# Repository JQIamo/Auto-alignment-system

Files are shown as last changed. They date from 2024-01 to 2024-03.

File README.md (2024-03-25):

# Source Code for Autoalignment System

This git repository contains the entire source code for the autoalignment
system described in {link to the paper}. It includes:

- `src/`: The firmware for the microcontroller (Teensy 4.1).
- `scripts/`: The python scripts, run on a host PC, to communicate with the microcontroller
  for manual control and diagnostic purposes.
- `calibration/`: A Jupyter notebook that calculate the $A$ matrix from calibration data.
-  `eagle/`: Eagle schematic and board files for fabricating the main control board and the detector boards.

Instructions for how to compile and use the source code are documented in each
individual folder.

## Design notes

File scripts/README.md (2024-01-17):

## Utility Scripts For Communication And Beam Visualization

The communication between the host PC and the microcontroller is achieved
through the serial connection to the microcontroller.

In order to have multiple scripts communicating with the microcontroller at the
same time, all communication are relayed through the script `comm.py`, which
talks to other scripts through ZMQ sockets.

- `comm.py`: Communication host. Dispatch the requests from other scripts to
  the microcontroller.
- `beam_visualize.py`: A GUI program, displays current beam position and
  the beam trajectory history.
- `disp_intensity.py`: A GUI program, displays the beam intensity history. This
  is for troubleshooting laser power fluctuations.
- `interactive_prompt.py`: Provide an interactive prompt, where the user can
  type in commands and those commands are relayed to the microcontroller. This
  is the primary way of manually controlling the microcontroller.
- `move_motor.py`: Move the motor back and forth and collecting the PSD
  readings at the same time. This is for acquiring the calibration data.
- `utils.py`: Utilities functions.

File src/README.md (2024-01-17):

## Firmware for Teensy 4.1 Microcontroller

The firmware presented here is a self-contained Arduino project. It performs
the autoalignment task by itself at the request of a host PC.

### To Compile

The most straight-forward way of setting up the development environment is to
install the [Arduino IDE with teensy packages](https://www.pjrc.com/teensy/td_download.html).
Another way is to install the [`arduino-cli`](https://arduino.github.io/arduino-cli/0.35/)
and manually add the support of Teensy to it (see [the tutorial here](
https://arduino.github.io/arduino-cli/0.35/getting-started/#adding-3rd-party-cores) ).

The code makes use of FreeRTOS for task management, as described in the
manuscript. To compile, it is necessary to install the Arduino package
[`tsandmann/freertos-teensy`](https://github.com/tsandmann/freertos-teensy)
first.

Assuming `arduino-cli` is installed, this can be done by running
```
arduino-cli lib install --git-url https://github.com/tsandmann/freertos-teensy
```
To compile, go the `src/` folder and run
```
arduino-cli compile --build-path build --fqbn teensy:avr:teensy41 main
```

The compiled hex file will be outputted into `build/` folder.

Note that the upload functionality provided in Arduino is not very mature. A
more reliable way is to download
[`teensy_loader_cli`](https://www.pjrc.com/teensy/loader_cli.html) to upload
the hex file to the Teensy:
```
./teensy_loader_cli --mcu=TEENSY41 -s -v build/main.ino.hex
```

### Descriptions For Each File

- `BoardConnection.h`: Describing the pin connections and other hardware
  setups, including the PSD calibration information.
- `PositionMotionMatrices.h`: Storing the A-matrix calibration.
- `main.ino`: Initializing all tasks, interfacing the serial interface and
  dispatching control calls.
- `BeamDetection.cpp`: Reading PSD data, converting to position information.
-  `BeamPositionControl.cpp`: Calculating the motor movement needed to move
   from the current beam position to the desired beam position.
- `MotorControl.cpp`: Controlling the motors.
- `PeakDetection.cpp`: Algorithms to detect the peaks from the scanned cavity
  signals. This is part optional and can be disabled in `main.ino`.

### Before Use

Calibrations for the PSDs and the A-matrix are required for successful
operation. Those calibrations should be performed as instructed in
`calibration/` and the results should be stored in `BoardConnection.h`
and `PositionMotionMatrices.h`.

### Control Interface

When the microcontroller is running, it listens to the serial port for incoming
instructions:
- `pp`: Print beam position, in PSD units.
- `m {n} {step}`: Move the `n`-th motor with number of steps specified by
  `{step}`.
- `mp {x1} {x2} {y1} {y2}`: Move the beam to position specified by (`x1`, `y1`,
  `x2`, `y2`). This is the very command to achieve "autoalignment".
- `unmute`: Start PSD position logging. Useful when running calibrations.
- `mute`: Stop PSD position logging.

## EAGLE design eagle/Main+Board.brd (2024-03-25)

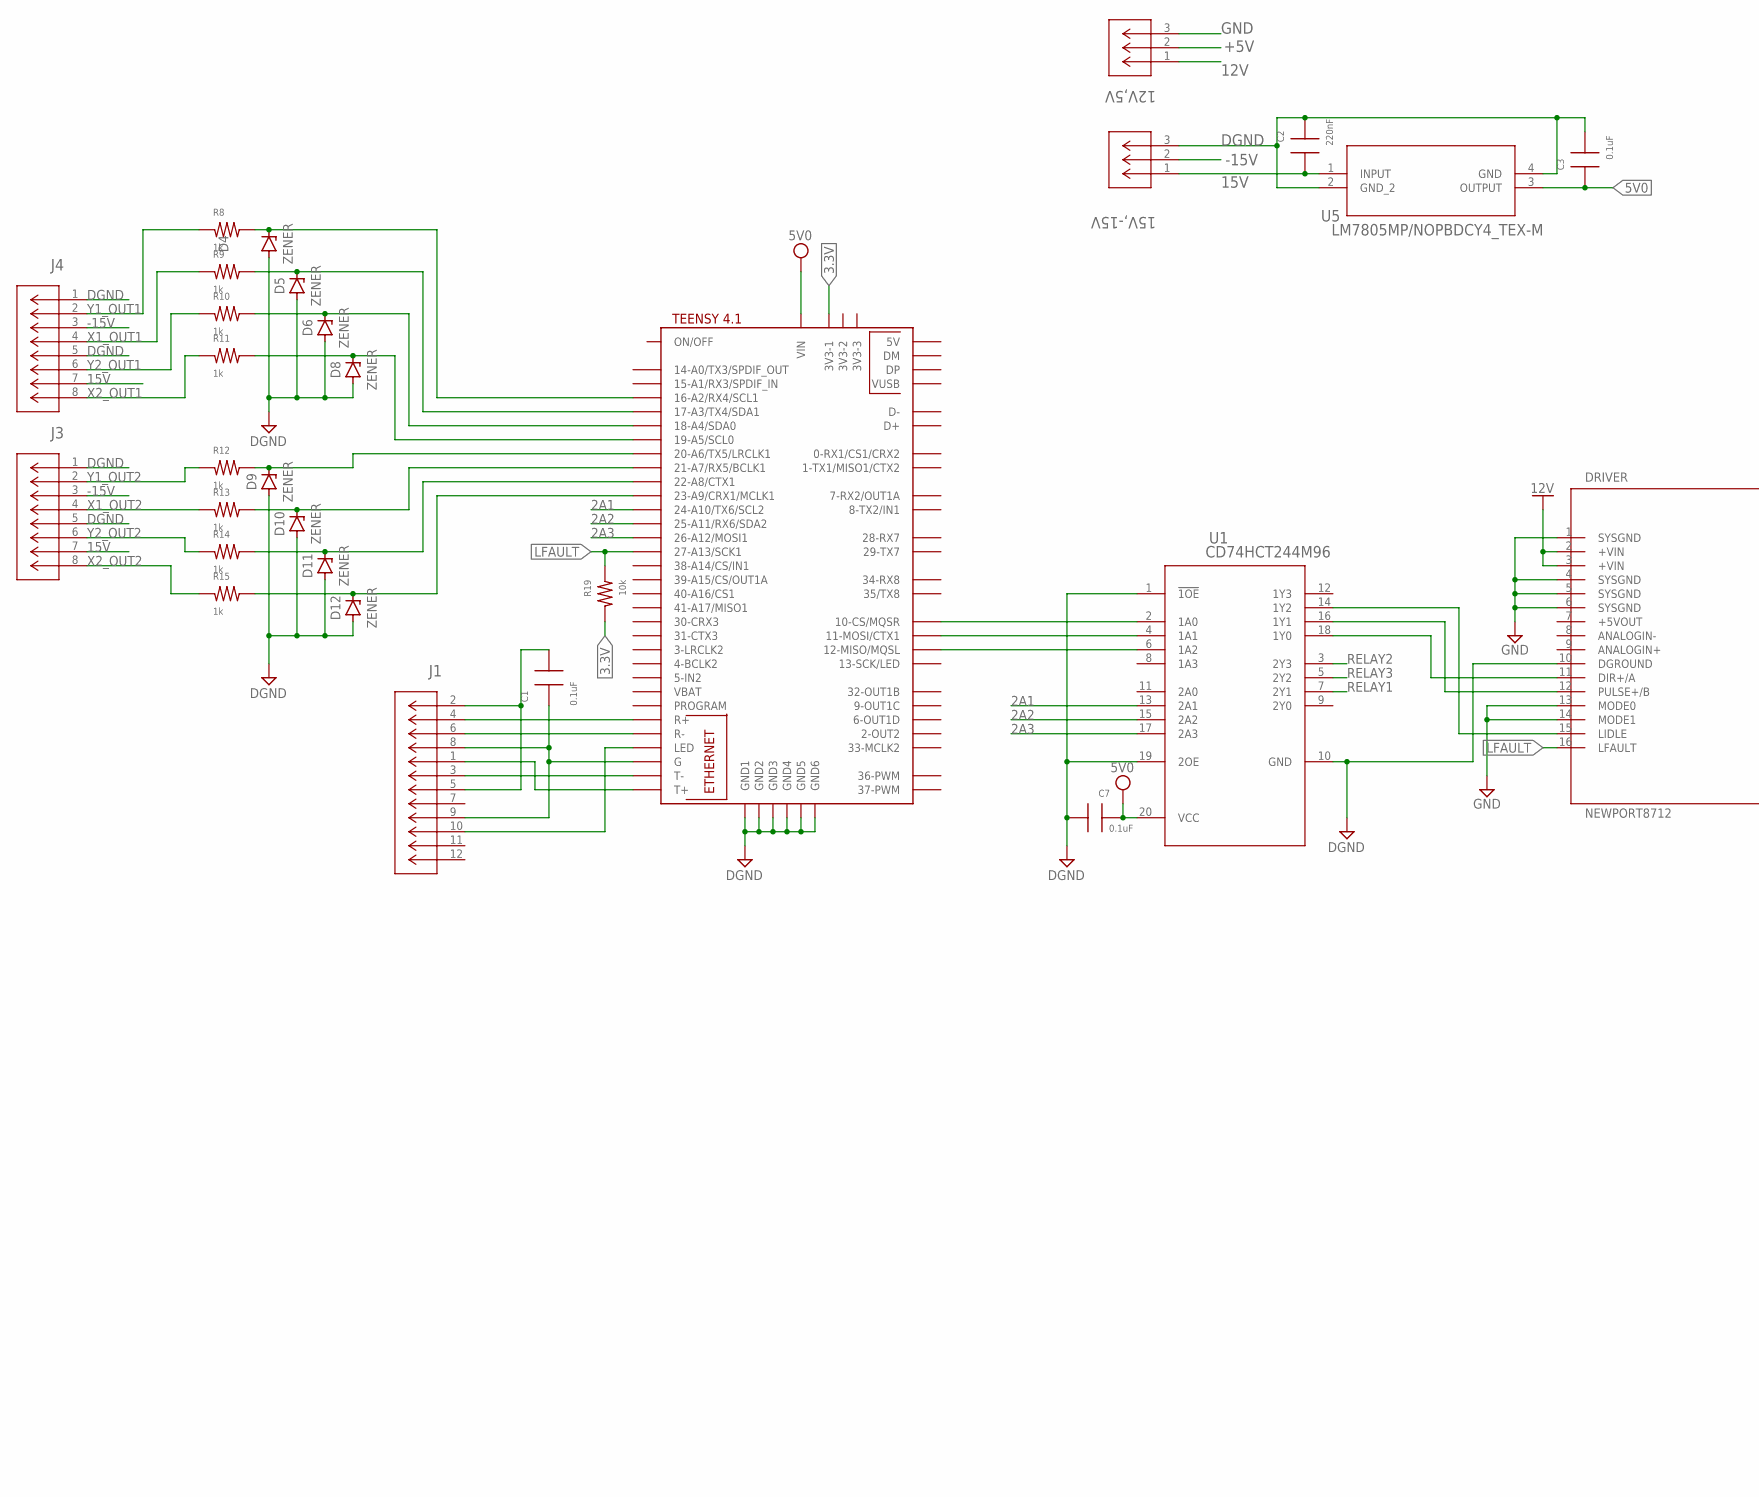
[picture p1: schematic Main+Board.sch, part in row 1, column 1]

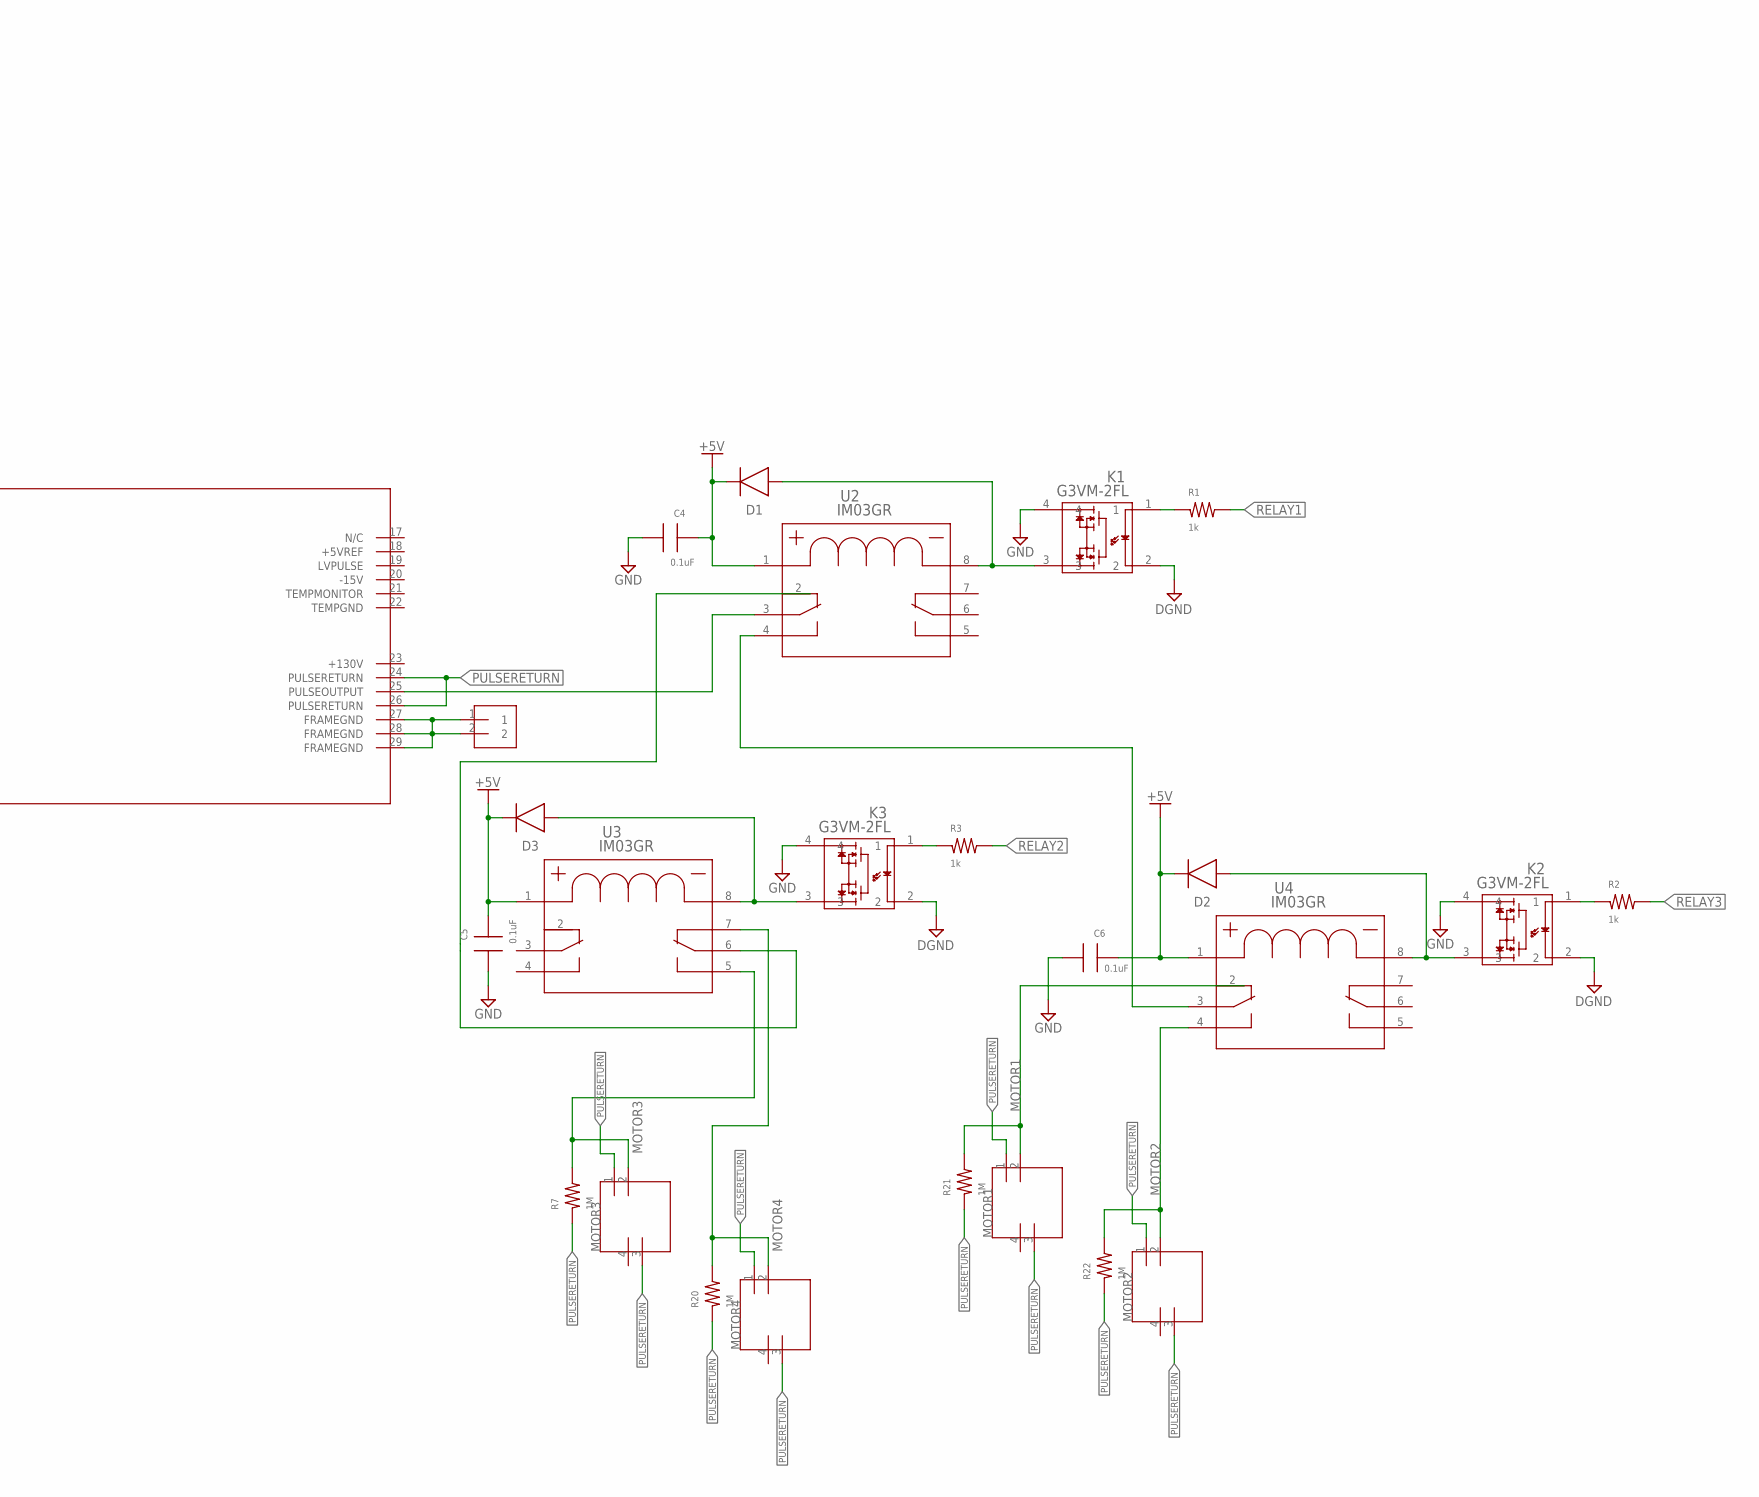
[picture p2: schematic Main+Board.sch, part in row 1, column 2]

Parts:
12V,5V, 15V,-15V: 1729021; CONN_1729021_PXC; DIGIKEY 277-1237-ND
C1, C3, C4, C5, C6, C7: 0.1uF; 0603; DIGIKEY 478-7018-1-ND
C2: 220nF; 0603; DIGIKEY 732-7991-1-ND
D1, D2, D3: 1N4448W; SOD3715X135; DIGIKEY 2721-1N4148WTR-ND
D4, D5, D6, D8, D9, D10, D11, D12: ZENER; SODFL3718X115; DIGIKEY 846-KDZVTR3.3BCT-ND
DRIVER: NEWPORT8712
J1: J1B1211CCD; CONN12_J1B1211CCD_WIZ; DIGIKEY 1278-1052-ND
J3, J4: 75869-332LF; CONN_332LF_AMP; DIGIKEY 609-5123-ND
K1, K2, K3: G3VM-2FL; A-DIP4_THD_OMR; DIGIKEY Z2711-ND
MOTOR1, MOTOR2, MOTOR3, MOTOR4: TM5RJ3-44; DIGIKEY H11287-ND
R1, R2, R3, R8, R9, R10, R11, R12, R13, R14, R15: 1k; 0603; DIGIKEY P123733CT-ND
R7, R20, R21, R22: 1M; 1210; DIGIKEY 13-RC1210FR-071MLCT-ND
R19: 10k; 0603; DIGIKEY YAG1236CT-ND
U1: CD74HCT244M96; DW20; DIGIKEY 296-14552-1-ND
U2, U3, U4: IM03GR; RELAY8-239X396_230; DIGIKEY PB1061CT-ND
U5: LM7805MP/NOPBDCY4_TEX-M; DCY4_TEX-M; DIGIKEY 296-44517-1-ND
U$1: TEENSY41; DIGIKEY 1568-DEV-16771-ND
U$2: 360272; DIGIKEY 1849-1246-ND

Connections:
2A1: U1.13 (2A1), U$1.24-A10/TX6/SCL2
2A2: U1.15 (2A2), U$1.25-A11/RX6/SDA2
2A3: U1.17 (2A3), U$1.26-A12/MOSI1
3.3V: R19.2, U$1.3V3-1
5V0: C3.1, C7.2, U1.20 (VCC), U5.3 (OUTPUT), U$1.VIN
12V: 12V,5V.1, DRIVER.2 (+VIN), DRIVER.3 (+VIN)
15V: 15V,-15V.1, C2.1, J3.7, J4.7, U5.1 (INPUT)
+5V: 12V,5V.2, C4.2, C5.2, C6.2, D1.1 (C), D2.1 (C), D3.1 (C), U2.1, U3.1, U4.1
-15V: 15V,-15V.2, J3.3, J4.3
DGND: 15V,-15V.3, C2.2, C3.2, C7.1, D4.2 (A), D5.2 (A), D6.2 (A), D8.2 (A), D9.2 (A), D10.2 (A), D11.2 (A), D12.2 (A), DRIVER.10 (DGROUND), J3.1, J3.5, J4.1, J4.5, K1.2, K2.2, K3.2, U1.1 (!1OE), U1.10 (GND), U1.19 (2OE), U5.2 (GND_2), U5.4 (GND), U$1.GND1, U$1.GND2, U$1.GND3, U$1.GND4, U$1.GND5, U$1.GND6
FRAMEGND: DRIVER.27 (FRAMEGND), DRIVER.28 (FRAMEGND), DRIVER.29 (FRAMEGND), U$2.1, U$2.2
GND: 12V,5V.3, C4.1, C5.1, C6.1, DRIVER.1 (SYSGND), DRIVER.4 (SYSGND), DRIVER.5 (SYSGND), DRIVER.6 (SYSGND), DRIVER.13 (MODE0), DRIVER.14 (MODE1), K1.4, K2.4, K3.4
LFAULT: DRIVER.16 (LFAULT), R19.1, U$1.27-A13/SCK1
MOTOR1: MOTOR1.2, R21.2, U4.2
MOTOR2: MOTOR2.2, R22.2, U4.4
MOTOR3: MOTOR3.2, R7.2, U3.5
MOTOR4: MOTOR4.2, R20.2, U3.7
unnamed: D10.1 (C), R13.2, U$1.21-A7/RX5/BCLK1
unnamed: K1.1, R1.1
unnamed: D4.1 (C), R8.2, U$1.16-A2/RX4/SCL1
unnamed: D5.1 (C), R9.2, U$1.17-A3/TX4/SDA1
unnamed: D6.1 (C), R10.2, U$1.18-A4/SDA0
unnamed: D8.1 (C), R11.2, U$1.19-A5/SCL0
unnamed: U1.2 (1A0), U$1.10-CS\MQSR (10-CS/MQSR)
unnamed: U1.4 (1A1), U$1.11-MOSI/CTX1
unnamed: U1.6 (1A2), U$1.12-MISO/MQSL
unnamed: K2.1, R2.1
unnamed: K3.1, R3.1
unnamed: C1.2, J1.2, J1.5
unnamed: DRIVER.15 (LIDLE), U1.14 (1Y2)
unnamed: DRIVER.12 (PULSE+/B), U1.16 (1Y1)
unnamed: DRIVER.11 (DIR+/A), U1.18 (1Y0)
unnamed: D3.2 (A), K3.3, U3.8
unnamed: D9.1 (C), R12.2, U$1.20-A6/TX5/LRCLK1
unnamed: U2.2, U3.6
unnamed: U2.4, U4.3
unnamed: D1.2 (A), K1.3, U2.8
unnamed: D2.2 (A), K2.3, U4.8
unnamed: D12.1 (C), R15.2, U$1.23-A9/CRX1/MCLK1
unnamed: D11.1 (C), R14.2, U$1.22-A8/CTX1
unnamed: C1.1, J1.8, J1.9, U$1.G
unnamed: J1.10, U$1.LED
PULSEOUTPUT: DRIVER.25 (PULSEOUTPUT), U2.3
PULSERETURN: DRIVER.24 (PULSERETURN), DRIVER.26 (PULSERETURN), MOTOR1.1, MOTOR1.3, MOTOR2.1, MOTOR2.3, MOTOR3.1, MOTOR3.3, MOTOR4.1, MOTOR4.3, R7.1, R20.1, R21.1, R22.1
RELAY1: R1.2, U1.7 (2Y1)
RELAY2: R3.2, U1.3 (2Y3)
RELAY3: R2.2, U1.5 (2Y2)
R_N: J1.6, U$1.R-
R_P: J1.4, U$1.R+
T_N: J1.3, U$1.T-
T_P: J1.1, U$1.T+
X1_OUT1: J4.4, R9.1
X1_OUT2: J3.4, R13.1
X2_OUT1: J4.8, R11.1
X2_OUT2: J3.8, R15.1
Y1_OUT1: J4.2, R8.1
Y1_OUT2: J3.2, R12.1
Y2_OUT1: J4.6, R10.1
Y2_OUT2: J3.6, R14.1

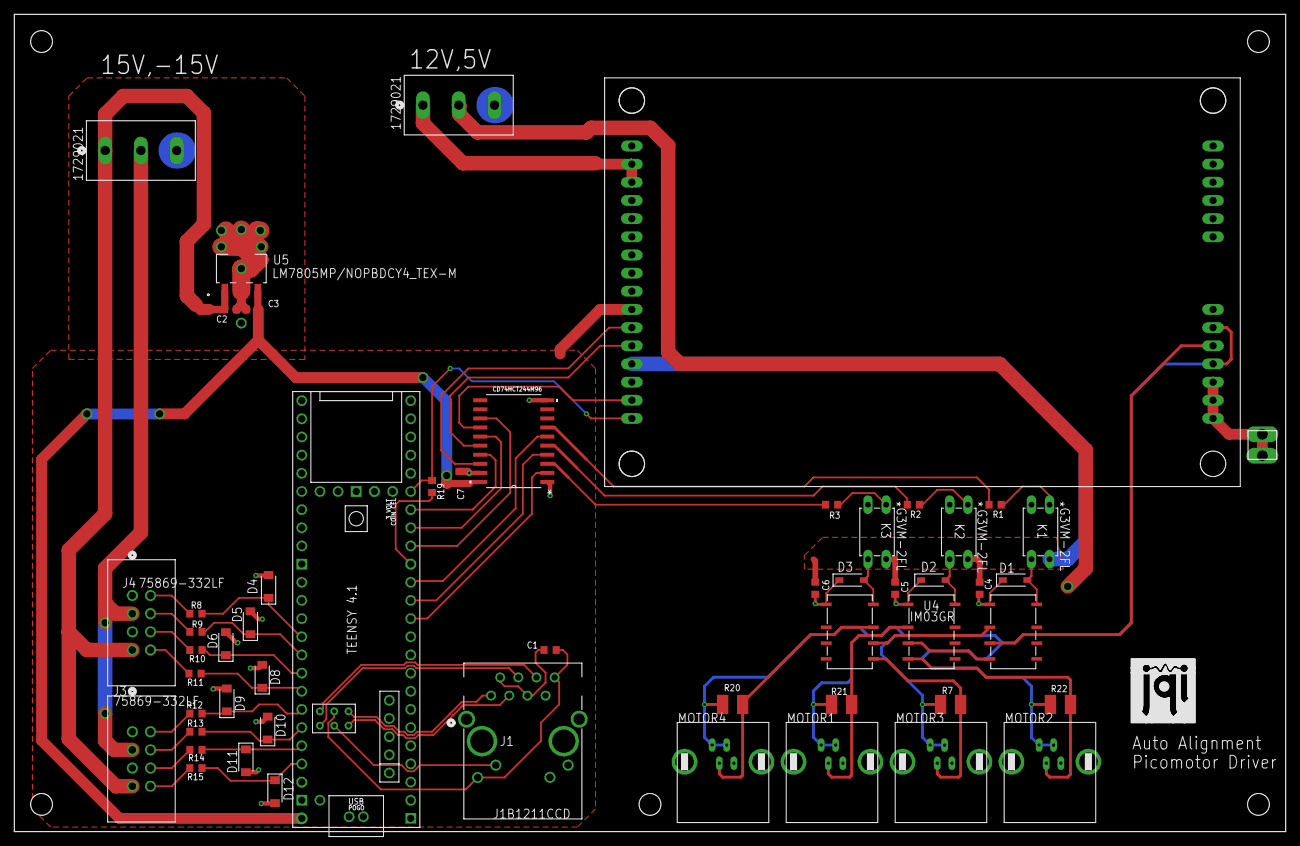
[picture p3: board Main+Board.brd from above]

Board: 2 copper layers, 177.8 x 114.3 mm, 56 parts (0 on the bottom side), 59 nets.

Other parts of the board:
LOGO1: JQI-LOGOSILK; JQI_LOGO_NEGATIVE-SILKSCREEN@1
U$3: AUTOALIGNMENT

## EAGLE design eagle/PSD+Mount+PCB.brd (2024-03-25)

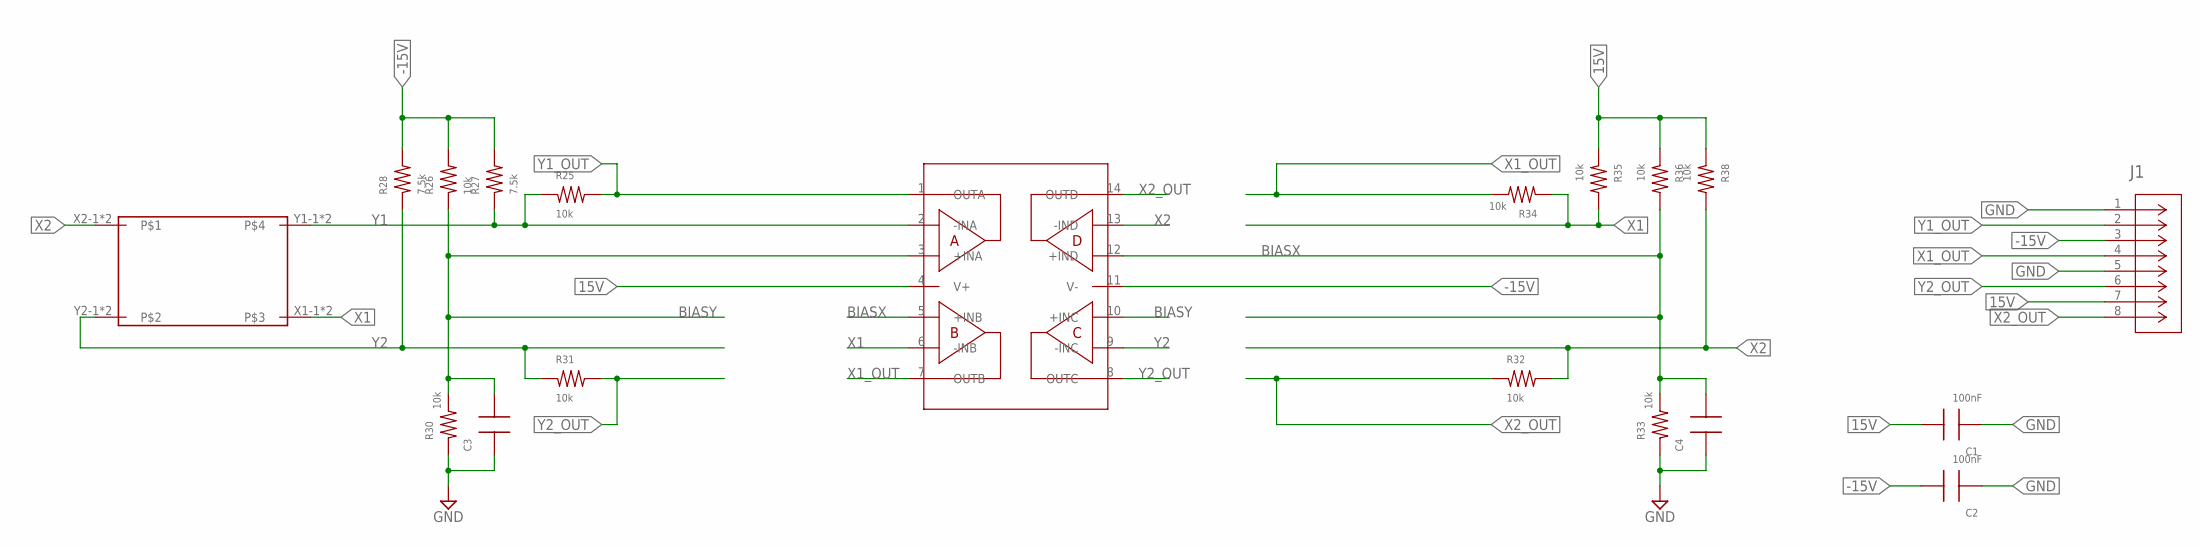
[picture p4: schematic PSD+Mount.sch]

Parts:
AMP1: OPA4140; SOP65P640X120-14N; DIGIKEY 296-46322-1-ND
C1, C2: 100nF; 0603; DIGIKEY 478-7018-1-ND
C3, C4: CAP0603; 0603; DIGIKEY 478-7018-1-ND
J1: 75869-332LF; CONN_332LF_AMP; DIGIKEY 609-5123-ND
R25, R26, R30, R31, R32, R33, R34, R35, R36, R38: 10k; 0603; DIGIKEY YAG1236CT-ND
R27, R28: 7.5k; 0603; DIGIKEY YAG1236CT-ND
U$1: 2L10UV_SU7

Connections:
15V: AMP1.4 (V+), C1.2, J1.7, R35.1, R36.1, R38.1
-15V: AMP1.11 (V-), C2.2, J1.3, R26.2, R27.2, R28.2
BIASX: AMP1.5 (+INB), AMP1.12 (+IND), C4.2, R33.2, R36.2
BIASY: AMP1.3 (+INA), AMP1.10 (+INC), C3.2, R26.1, R30.2
GND: C1.1, C2.1, C3.1, C4.1, J1.1, J1.5, R30.1, R33.1
X1: AMP1.6 (-INB), R34.1, R35.2, U$1.X1-1, U$1.X1-2
X1_OUT: AMP1.7 (OUTB), J1.4, R34.2
X2: AMP1.13 (-IND), R32.2, R38.2, U$1.X2-1, U$1.X2-2
X2_OUT: AMP1.14 (OUTD), J1.8, R32.1
Y1: AMP1.2 (-INA), R25.1, R27.1, U$1.Y1-1, U$1.Y1-2
Y1_OUT: AMP1.1 (OUTA), J1.2, R25.2
Y2: AMP1.9 (-INC), R28.1, R31.1, U$1.Y2-1, U$1.Y2-2
Y2_OUT: AMP1.8 (OUTC), J1.6, R31.2

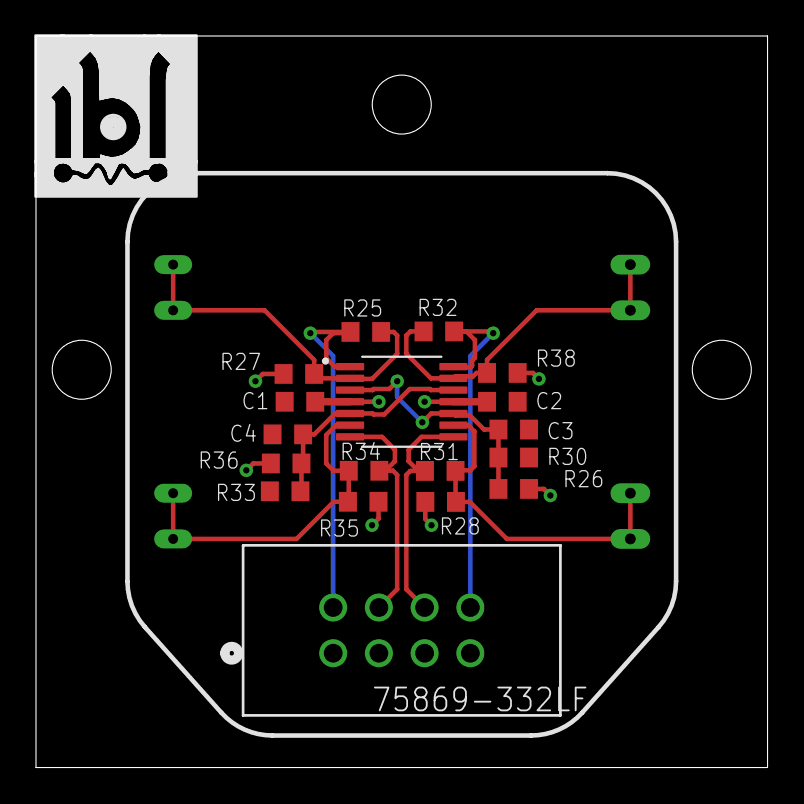
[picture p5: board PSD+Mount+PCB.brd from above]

Board: 4 copper layers, 40.6 x 40.6 mm, 20 parts (1 on the bottom side), 13 nets.

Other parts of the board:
LOGO1: JQI-LOGOSILK; JQI_LOGO_NEGATIVE-SILKSCREEN@1

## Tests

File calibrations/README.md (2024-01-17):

## Calibration Notebook And Data

An annotated Jupyter notebook used to produce the A-matrix is provided in this
folder. It includes plotting, fitting, and error analysis.

The example data from one of the test calibrations we have performed is stored
in `data.zip`. The notebook runs against the data inside.

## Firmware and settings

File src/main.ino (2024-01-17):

#include "Arduino.h"
#include "arduino_freertos.h"
#include "avr/pgmspace.h"

#include "BoardConnection.h"
#include "BeamDetection.h"
#include "PeakDetection.h"
#include "MotorControl.h"
#include "BeamPositionControl.h"

#include "PositionMotionMatrices.h"

char inputBuffer[200];
int inputLen;

bool mute = false;

void peakCountTask(void*)
{
	uint32_t peak_cnt;
	for (;;) {
		if (::xQueueReceive(peakCountQueue, (void *) &peak_cnt, portMAX_DELAY) == pdTRUE)
		if (!mute) ::Serial.printf("peak_count %d\r\n", peak_cnt);
	}
}

FLASHMEM __attribute__((noinline)) void setup()
{
	::analogReadResolution(12);

	::pinMode(arduino::LED_BUILTIN, arduino::OUTPUT);

	inputLen = 0;

	::Serial.begin(115200);

	delay(200);

	initBeamLocator();
	setupPSDLogging(true);
	initPeakDetection(20, 10);  // this is optional
	initMotors();
	initBeamPositionControl(&psdReadoutQueue);

	::xTaskCreate(serialInputDispatchTask, "serialInputDispatchTask", 1024, nullptr, 2, nullptr);
	::xTaskCreate(peakCountTask, "peakCountTask", 128, nullptr, 2, nullptr);

	::vTaskStartScheduler();
}

void loop() { }

static void serialInputDispatchTask(void*)
{
        char c;
        int arg1, arg2, arg3, arg4;
        float arg5, arg6, arg7, arg8;
        while (true) {
                if(!::Serial.available()) {
                        taskYIELD();
                        continue;
                }

                c = Serial.read();
                if (c != '\n' && c != '\r' && inputLen < 200 - 2) {
                        inputBuffer[inputLen] = c;
                        inputBuffer[inputLen + 1] = '\0';
                        ++inputLen;
                        continue;
                } else {
                        inputBuffer[inputLen] = '\0';
                        inputLen = 0;
                }

                if (strcmp(inputBuffer, "mute") == 0) {
			setupPSDLogging(false);
			mute = true;
		} else if (strcmp(inputBuffer, "unmute") == 0) {
			mute = false;
			setupPSDLogging(true);
		} else if (strcmp(inputBuffer, "pp") == 0) {
			printLastBeamPosition();
		} else if (sscanf(inputBuffer, "m %d %d", &arg1, &arg2) == 2) {
                        ::Serial.printf("] Motor %d move step %d\r\n", arg1, arg2);

                        if (arg2 == 0) continue;

                        switch (arg1) {
                                case 1: moveMotor(MIRROR1_X_MOTOR, (arg2 > 0), 800, abs(arg2)); break;
                                case 2: moveMotor(MIRROR1_Y_MOTOR, (arg2 > 0), 800, abs(arg2)); break;
                                case 3: moveMotor(MIRROR2_X_MOTOR, (arg2 > 0), 800, abs(arg2)); break;
                                case 4: moveMotor(MIRROR2_Y_MOTOR, (arg2 > 0), 800, abs(arg2)); break;
                                default: break;
                        }
                } else if (sscanf(inputBuffer, "mm %d %d %d %d", &arg1, &arg2, &arg3, &arg4) == 4) {
                        ::Serial.printf("] Motor move step (%d, %d, %d, %d) \r\n", arg1, arg2, arg3, arg4);

                        IntVector4 delta_m = {{ arg1, arg2, arg3, arg4 }};
			moveMotors(&delta_m);
                } else if (sscanf(inputBuffer, "mp %f %f %f %f", &arg5, &arg6, &arg7, &arg8) == 4) {
                        ::Serial.printf("] Motor move to position (%.4f, %.4f, %.4f, %.4f) \r\n", arg5, arg6, arg7, arg8);

                        FloatVector4 dest_p = {{ arg5, arg6, arg7, arg8 }};
			moveBeamToPosition(&dest_p);
                } else {
			::Serial.println("?");
		}
        }
}

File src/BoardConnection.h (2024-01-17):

#ifndef BOARDCONNECTION_H_
#define BOARDCONNECTION_H_

// #define DETECTOR1 1
// #define DETECTOR2 2
//
#define DETECTOR1 0
#define DETECTOR2 1

#define D1_Y1_PIN 16
#define D1_X1_PIN 17
#define D1_Y2_PIN 18
#define D1_X2_PIN 19

#define D2_Y1_PIN 20
#define D2_X1_PIN 21
#define D2_Y2_PIN 22
#define D2_X2_PIN 23

#define MOTOR_DIRECTION_PIN 10

//pulse rate can be between 0 and 2kHz
#define MOTOR_PULSE_PIN 11
#define MOTOR_IDLE_PIN 12
#define RELAY1_PIN 24
#define RELAY2_PIN 26
#define RELAY3_PIN 25

#define PEAK_DET_TRIG_PIN 37
#define PEAK_DET_ADC_PIN 38 // A14
#define PEAK_DET_ADC_CH (128+1) // A14, on ADC2

typedef struct {
	uint8_t y1_pin;
	uint8_t x1_pin;
	uint8_t y2_pin;
	uint8_t x2_pin;
} PSDPin;

typedef struct {
	uint32_t y1_offset;
	uint32_t x1_offset;
	uint32_t y2_offset;
	uint32_t x2_offset;
} PSDOffset;

typedef struct {
	uint32_t x1_min;
	uint32_t x1_max;
	uint32_t x2_min;
	uint32_t x2_max;
	uint32_t y1_min;
	uint32_t y1_max;
	uint32_t y2_min;
	uint32_t y2_max;
} PSDReliableRange;

const PSDPin PSD1_PIN = {
	.y1_pin = 16, 
	.x1_pin = 17, 
	.y2_pin = 18, 
	.x2_pin = 19 
};

const PSDPin PSD2_PIN = {
	.y1_pin = 20, 
	.x1_pin = 21, 
	.y2_pin = 22, 
	.x2_pin = 23 
};

const PSDOffset PSD1_OFFSET = {
	.y1_offset = 3102, 
	.x1_offset = 0, 
	.y2_offset = 3085, 
	.x2_offset = 64 
};

const PSDOffset PSD2_OFFSET = {
	.y1_offset = 3126, 
	.x1_offset = 0, 
	.y2_offset = 3179, 
	.x2_offset = 0 
};

const PSDReliableRange PSD1_RANGE = {
	.x1_min = 500,
	.x1_max = 4000,
	.x2_min = 500,
	.x2_max = 4000,
	.y1_min = 100,
	.y1_max = 2600,
	.y2_min = 100,
	.y2_max = 2600,
};

const PSDReliableRange PSD2_RANGE = {
	.x1_min = 500,
	.x1_max = 4000,
	.x2_min = 500,
	.x2_max = 4000,
	.y1_min = 100,
	.y1_max = 2600,
	.y2_min = 100,
	.y2_max = 2600,
};

#define MIRROR1_X_MOTOR 0
#define MIRROR1_Y_MOTOR 1
#define MIRROR2_X_MOTOR 2
#define MIRROR2_Y_MOTOR 3

typedef struct MotorAddr {
	bool relay1;
	bool relay2;
	bool relay3;
} MotorAddr;

const MotorAddr motor1Addr = {
	.relay1 = false,
	.relay2 = false,
	.relay3 = false
};

const MotorAddr motor2Addr = {
	.relay1 = true,
	.relay2 = false,
	.relay3 = false
};

const MotorAddr motor3Addr = {
	.relay1 = false,
	.relay2 = true,
	.relay3 = false
};

const MotorAddr motor4Addr = {
	.relay1 = true,
	.relay2 = false,
	.relay3 = true
};

#endif

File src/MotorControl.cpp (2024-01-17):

#include "Arduino.h"
#include "arduino_freertos.h"

#include "MotorControl.h"

uint8_t current_motor;
bool motor_idle, motor_direction;


void moveMotors(const IntVector4 *motor_steps) {
	moveMotor(MIRROR1_X_MOTOR, (motor_steps->v[0] > 0), 800, abs(motor_steps->v[0]));
	moveMotor(MIRROR1_Y_MOTOR, (motor_steps->v[1] > 0), 800, abs(motor_steps->v[1]));
	moveMotor(MIRROR2_X_MOTOR, (motor_steps->v[2] > 0), 800, abs(motor_steps->v[2]));
	moveMotor(MIRROR2_Y_MOTOR, (motor_steps->v[3] > 0), 800, abs(motor_steps->v[3]));
}

void moveMotor(uint8_t motor, bool clockwise, uint32_t frequency, uint32_t step)
{
	::noTone(MOTOR_PULSE_PIN);

	if (motor != current_motor){
		switchMotor(motor);
	}

	if (motor_idle) {
		::digitalWriteFast(MOTOR_IDLE_PIN, arduino::HIGH);
		motor_idle = false;
		::vTaskDelay(pdMS_TO_TICKS(500));
	}

	if (motor_direction != clockwise){
		::digitalWriteFast(MOTOR_DIRECTION_PIN, (clockwise ? arduino::HIGH : arduino::LOW));
		motor_direction = clockwise;
		::vTaskDelay(pdMS_TO_TICKS(5));
	}

	uint32_t duration = 1000 * step / frequency;

	::Serial.printf("] Move m%d, direction %d, rate %d, step %d, duration %d\r\n", motor, clockwise, frequency, step, duration);

	if (duration > 0) {
		::tone(MOTOR_PULSE_PIN, frequency, duration); 
		::vTaskDelay(pdMS_TO_TICKS(duration));
	}
}

bool switchMotor(uint8_t motor)
{
	if (!motor_idle){
		::digitalWriteFast(MOTOR_IDLE_PIN, arduino::LOW);
		motor_idle = true;
		::vTaskDelay(pdMS_TO_TICKS(500));  // 500 ms is required by the datasheet to safely discharge picomotor.
	}

	if (motor >= MOTOR_CNT) return false;

	current_motor = motor;

	MotorAddr ma = motorAddrs[motor];
	::digitalWriteFast(RELAY1_PIN, ma.relay1);
	::digitalWriteFast(RELAY2_PIN, ma.relay2);
	::digitalWriteFast(RELAY3_PIN, ma.relay3);

	return true;
}

FLASHMEM __attribute__((noinline)) void initMotors() 
{
	::pinMode(RELAY1_PIN, arduino::OUTPUT);
	::pinMode(RELAY2_PIN, arduino::OUTPUT);
	::pinMode(RELAY3_PIN, arduino::OUTPUT);

	::pinMode(MOTOR_IDLE_PIN, arduino::OUTPUT);
	::pinMode(MOTOR_DIRECTION_PIN, arduino::OUTPUT);
	::pinMode(MOTOR_PULSE_PIN, arduino::OUTPUT);

	::digitalWriteFast(MOTOR_IDLE_PIN, arduino::LOW);
	motor_idle = true;
	::digitalWriteFast(MOTOR_DIRECTION_PIN, arduino::LOW);
	motor_direction = false;
}

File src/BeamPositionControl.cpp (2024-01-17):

#include "Arduino.h"
#include "math.h"
#include "arduino_freertos.h"
#include "queue.h"

#include "BeamPositionControl.h"
#include "BeamDetection.h"
#include "MotorControl.h"

bool running;
bool can_run;

::QueueHandle_t *psd_queue;

Point p1, p2, p1_var, p2_var;

void receivePSDDataTask(void*)
{
	PSDAvgData psd_readouts[2];

	PSDConversionError err1, err2;

	for (;;) {
		if (::xQueueReceive(*psd_queue, (void *) &psd_readouts, portMAX_DELAY) == pdTRUE) {
			const PSDAvgData d1 = psd_readouts[0];
			const PSDAvgData d2 = psd_readouts[1];

			err1 = convertPSDReadingtoPosition(0, &d1, &p1, &p1_var);
			err2 = convertPSDReadingtoPosition(1, &d2, &p2, &p2_var);

			can_run = (err1 == PSDConversionError::NO_ERROR && err2 == PSDConversionError::NO_ERROR);

                        // if (err1 == PSDConversionError::NO_ERROR) {
                        //         ::Serial.printf("> p1: (%.2f, %.2f), p1_var: (%.2f, %.2f) \r\n",
                        //                         p1.x, p1.y, p1_var.x, p1_var.y);
                        // } else {
                        //         ::Serial.printf("> p1: CONVERSION ERROR \r\n");
                        // }
 
                        // if (err2 == PSDConversionError::NO_ERROR) {
                        //         ::Serial.printf("> p2: (%.2f, %.2f), p2_var: (%.2f, %.2f) \r\n",
                        //                         p2.x, p2.y, p2_var.x, p2_var.y);
                        // } else {
                        //         ::Serial.printf("> p2: CONVERSION ERROR \r\n");
                        // }
		}
	}
}

void moveBeamToPosition(const FloatVector4 *dest_p) {
	FloatVector4 current_p = {{ p1.x, p1.y, p2.x, p2.y }};
	FloatVector4 delta_p;
	vectorDelta(dest_p, &current_p, &delta_p);
	::Serial.printf("] Delta p (%.5f, %.5f, %.5f, %.5f) \r\n", delta_p.v[0], delta_p.v[1], delta_p.v[2], delta_p.v[3]);

	IntVector4 delta_m = {{ 0, 0, 0, 0 }};
	matrixMul(&pMMatrices[0], &delta_p, &delta_m);
	matrixMul(&pMMatricesSelect(delta_m), &delta_p, &delta_m);

	::Serial.printf("] Motor move step (%d, %d, %d, %d) \r\n", delta_m.v[0], delta_m.v[1], delta_m.v[2], delta_m.v[3]);
	moveMotors(&delta_m);
}


void initBeamPositionControl(::QueueHandle_t *_psd_queue) {
	psd_queue = _psd_queue;
	::xTaskCreate(receivePSDDataTask, "receivePSDDataTask", 512, nullptr, 2, nullptr);
}

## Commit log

2024-01-17 Add calibration notebook and data
2024-03-25 Added all the eagle files for PCB fabrication
    [Main+Board.brd, Main+Board.sch, PSD+Mount+PCB.brd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]

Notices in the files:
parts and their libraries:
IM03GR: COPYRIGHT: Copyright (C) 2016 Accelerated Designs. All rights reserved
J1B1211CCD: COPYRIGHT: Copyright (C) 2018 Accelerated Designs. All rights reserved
